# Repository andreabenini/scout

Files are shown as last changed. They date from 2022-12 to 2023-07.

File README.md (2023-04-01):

# scout
All terrain six wheeled scout robot (ATWSC). For fun and the sake of doing it.  
Project inspired by rocker-bogie designs mostly popularized by NASA Mars Missions and
developed around 1988 in JPL Labs. Sojourner was the first wheeled vehicle to rove on
a planet other than Earth, rocker-bogie was used due to its reliability.

---

The rocker-bogie design is unsprung and uses split rather than full-width axles,
allowing the rover to climb over obstacles that are up to twice the wheel's diameter in size
while keeping all six wheels on the ground.  
Systems using springs tend to tip more easily as the loaded side yields.

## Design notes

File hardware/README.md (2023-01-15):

# Raspberry Pi Wiring connections
```mermaid
flowchart LR
    VDC  ---|3.3v | 1...2
    SDA1 ---|SDA  | 3...4
    SCL1 ---|SCL  | 5...6
                    7...8  ---|GPIO14| B_1
    gnd  ---|GND  | 9...10 ---|GPIO15| B_2
                   11...12 ---|GPIO18| B_3
                   13...14 ---|GND   | B_gnd

    subgraph GPIO
         1...2
         3...4
         5...6
         7...8
         9...10
        11...12
        13...14
    end
    subgraph I2C
        VDC
        SDA1
        SCL1
        gnd
    end
    subgraph Buttons
        direction LR
        B_1
        B_2
        B_3
        B_gnd
    end
```

# PCA 9685 Connection Schema
| PCA 9685  | Pro Micro | _notes_ |
|:---:|:---:|---|
| **GND** | GND | |
| **OE** | __ | _not connected_ |
| **SCL** | SCL | _ProMicro SCL_ |
| **SDA** | SDA | _ProMicro SDA_ |
| **VCC** | RAW | _5v input from RAW_ |
| **V+** | __ | _not connected_ |

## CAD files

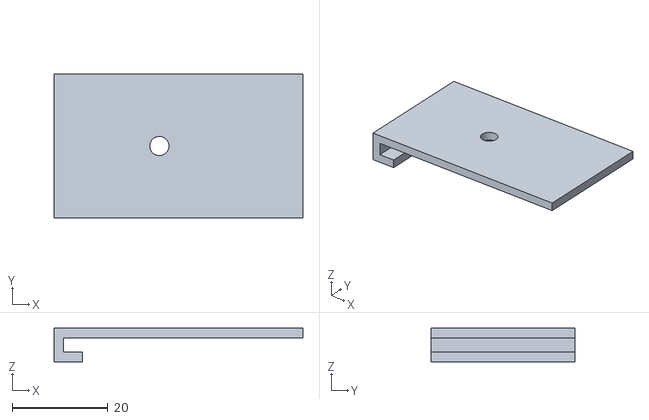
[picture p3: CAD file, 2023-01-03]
hardware/Chassis-Button Base.stl
52.0 x 30.0 x 7.00

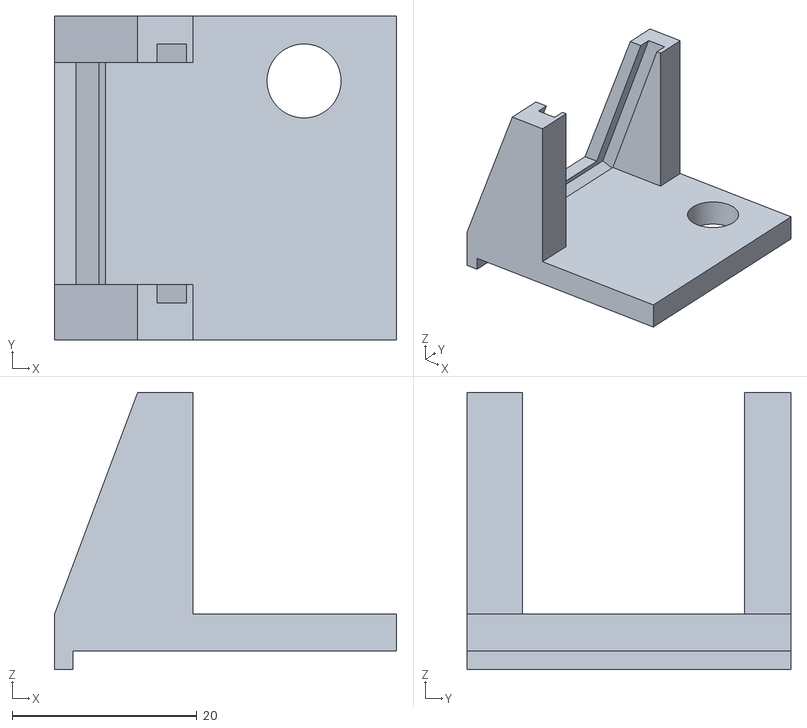
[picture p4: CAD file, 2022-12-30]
hardware/Chassis-service monitor holder.stl
37.0 x 35.0 x 30.0

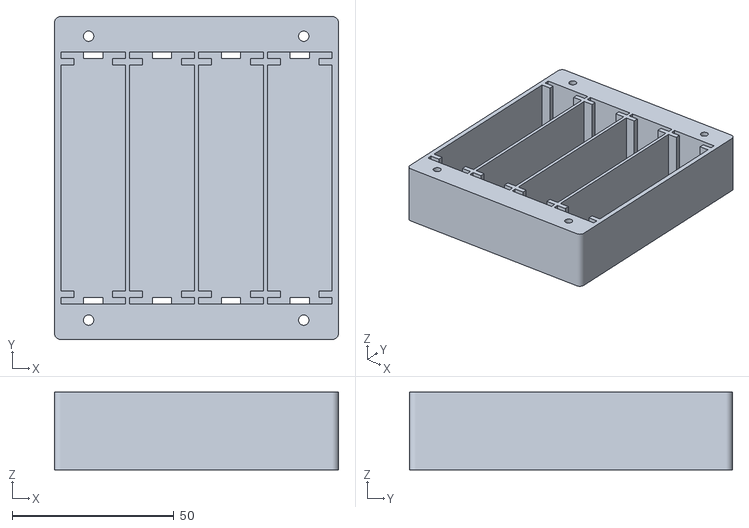
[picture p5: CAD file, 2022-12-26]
hardware/battery pack-BatteryBox.stl
88.0 x 100.0 x 24.0

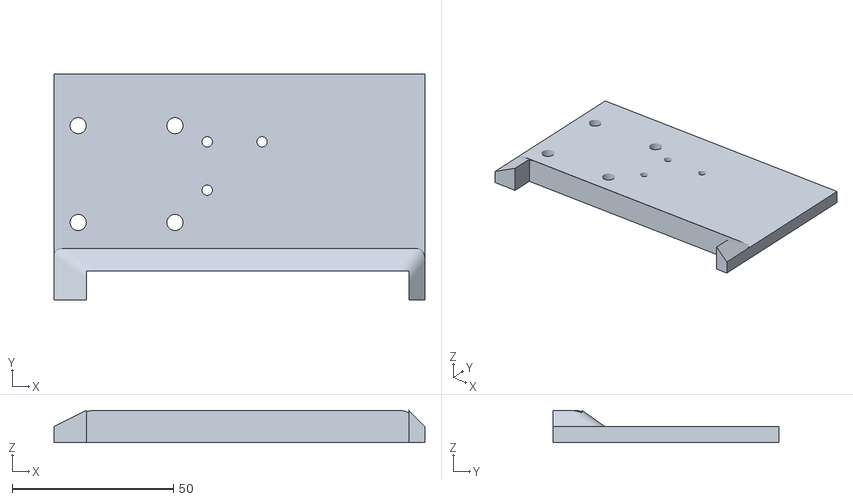
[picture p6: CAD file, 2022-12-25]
hardware/Chassis-Wing Left.stl
115.0 x 70.0 x 10.0

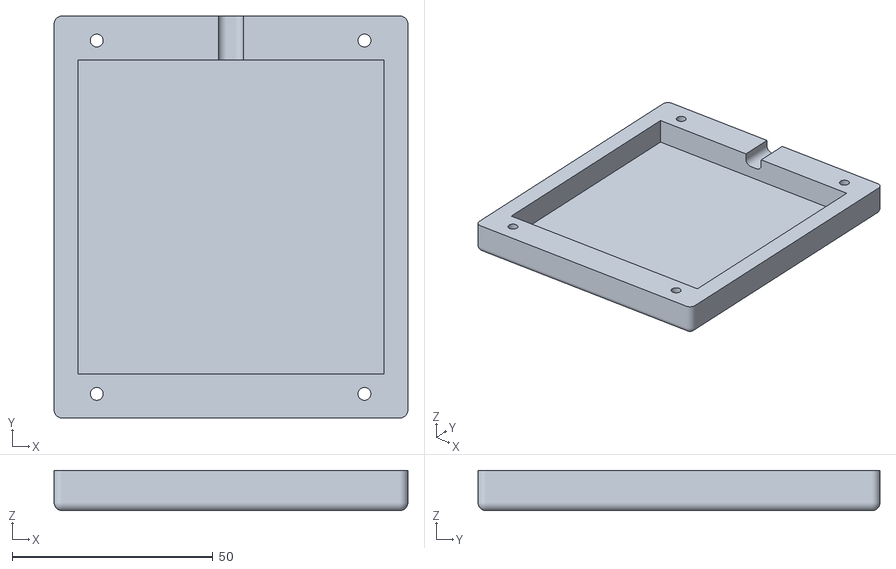
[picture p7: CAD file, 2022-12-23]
hardware/battery pack-Battery Bottom.stl
88.0 x 100.0 x 10.0

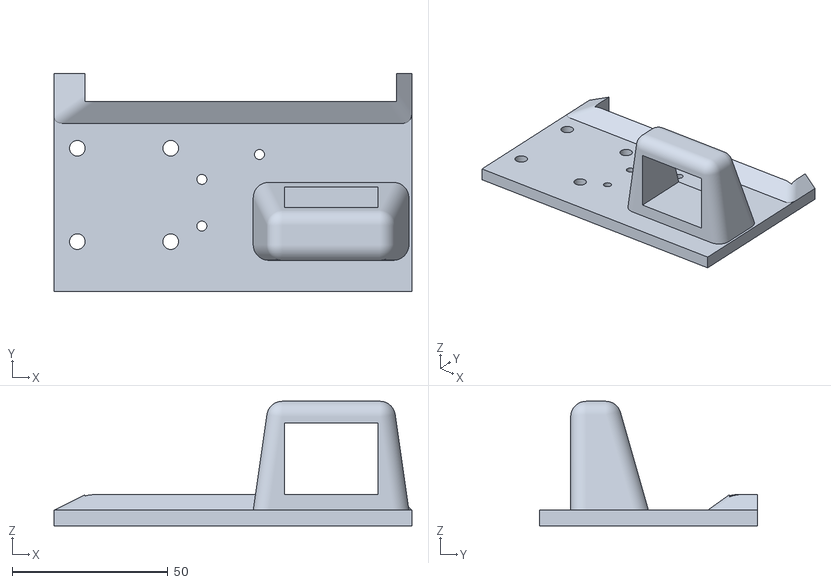
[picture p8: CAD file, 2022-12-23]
hardware/Chassis-Wing Right.stl
115.0 x 70.0 x 40.0

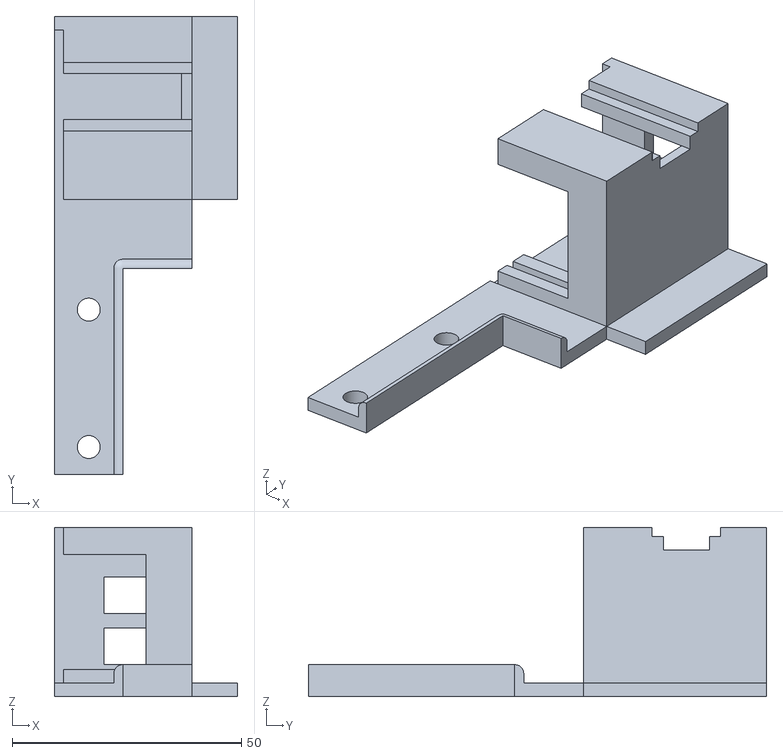
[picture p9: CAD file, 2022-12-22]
hardware/Chassis-Power Strip Box.stl
40.0 x 100.0 x 37.0

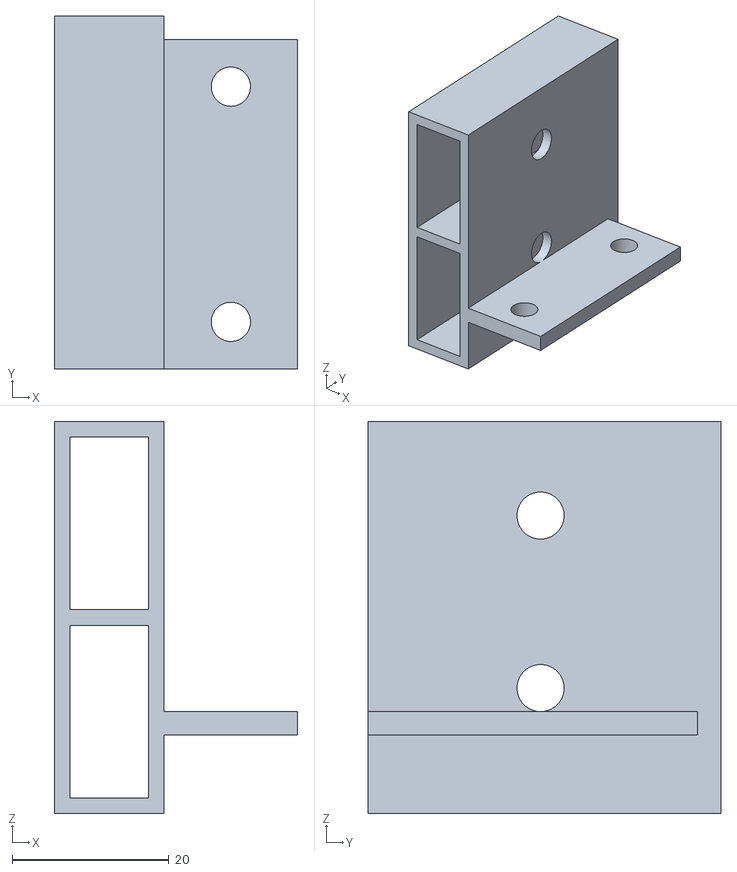
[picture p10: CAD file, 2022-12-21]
hardware/Chassis-UBECs.stl
31.0 x 45.0 x 50.0

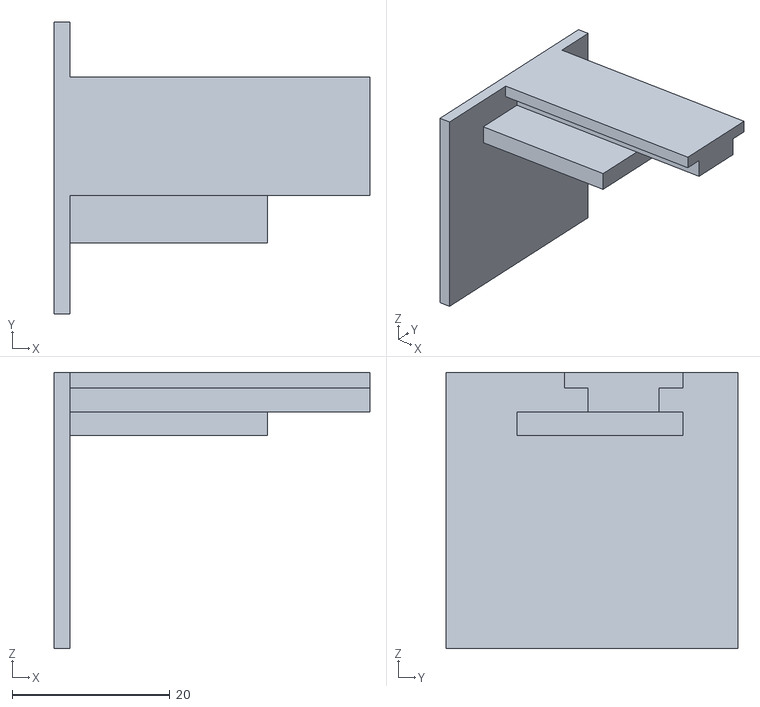
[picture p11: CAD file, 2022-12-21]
hardware/Chassis-Power Strip Cover.stl
40.0 x 37.0 x 35.0

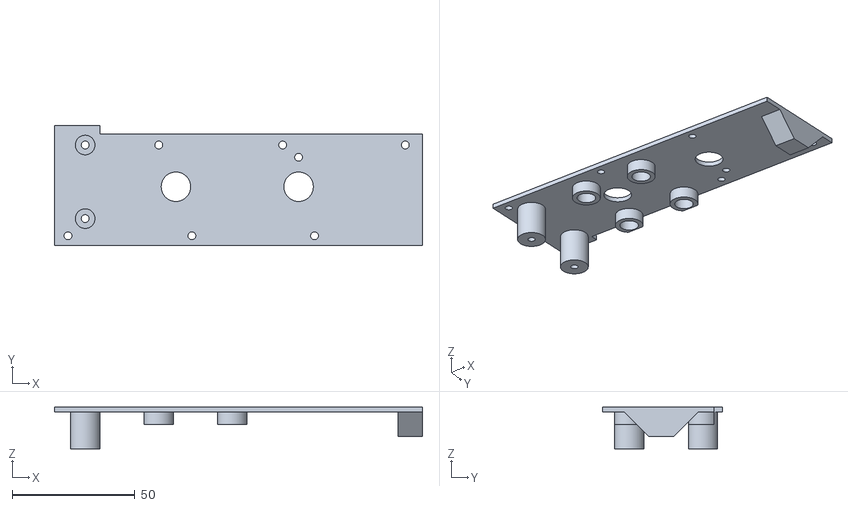
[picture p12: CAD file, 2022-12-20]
hardware/Chassis-HBridge Deck.stl
150.0 x 49.0 x 17.0

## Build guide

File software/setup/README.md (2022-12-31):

# System Setup

## Required Packages
These packages are needed for barebone software setup, everything else will
be installed as a dependency
- git
- gcc
- rsync
- i2c-tools  
    I2C Devices
- python
- python-pillow  
    I2C oled display

## I2C Setup
**/boot/config.txt**
```
dtparam=i2c_arm=on
```
**/etc/modules-load.d/raspberrypi.conf**, add i2c kernel module to this file
```sh
i2c-dev
```
### System check
- `lsmod |grep i2c_dev`
- `ls -la /dev/i2c-1`, might be _i2c-0_ if you've an older machine. 
    **i2c-20**, **i2c-21** are the HDMI output ports
- `i2cdetect -y 1`, where **1** is related to `i2c-1`, change it accordingly.
    This should print the I2C setup on GPIO port 1
- `i2cdetect -l`, displays the list of I2C Buses available in your system. Reference
    to i2c-20 and i2c-21 to **Broadcom STB** are related to HDMI ports

## Python Virtual Enviornment
These packages are needed, create a virtual environment and install them all in this order.
There's no need to execute everything in a privileged environment, normal user is preferred.
- wheel
- adafruit-circuitpython-ssd1306  
    I2C oled display
- RPi-GPIO
- Pillow  
    I2C oled graphical capabilities and animations

### I2C Display Samples
- **PREFERRED**, use this library for some OLED display samples:  
    https://github.com/adafruit/Adafruit_CircuitPython_SSD1306  
    This one is using CircuitPython libs
- **DEPRECATED**, do _NOT_ use this one:  
    https://github.com/adafruit/Adafruit_Python_SSD1306  
    this lib is still using the old _python-wiring_ as backend, it has
    been discontinued from RPi Foundation, use circuit python based one

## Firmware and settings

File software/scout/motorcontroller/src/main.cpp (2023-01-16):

// Libraries defines
#include <Arduino.h>
#include <Adafruit_PWMServoDriver.h>

// Global variables
byte iCommand;
char BUFFER[200];
char Command[50];

// Project defines
#include "defines.h"
#include "common.h"
#include "motor.h"
#include "communication.h"


/**
 * Global variables
 */
Adafruit_PWMServoDriver pwm;


/**
 * setup() - Constructor
 */
void setup() {
    serialConnect();
    motorInit();
} /**/


/**
 * loop() - MAIN LOOP
 */
void loop() {
    // Command detection
    if (iCommand > 0) {
        serialGetCommand();
        if (!strncmp_P(Command, CMD_MOTOR, strlen_P(CMD_MOTOR))) {
            motorCommand(Command);
        } else if (!strcmp_P(Command, CMD_INFO)) {
            Serial.println(FPrintCMD(INFO_VERSION));
        } else {
            Serial.print(FPrintCMD(CMD_ERROR));
            Serial.print(FPrint(" command: "));
            Serial.println(Command);
        }
    }
    delay(MAIN_LOOP_DELAY);
} /**/


/**
 * Generic serial event function, all results ALWAYS in [BUFFER], use [isBuffer] to check if it's complete
 */
void serialEvent() {
    while (Serial.available()) {
        int  iLen  = strlen(BUFFER);
        char iChar = (char)Serial.read();
        BUFFER[iLen] = iChar;
        BUFFER[iLen+1] = '\0';
        if (iChar == '\n') {
            iCommand++;
        }
    }
} /**/
/** NOTE: ProMicro does NOT use standard 'serialEvent()' but 'serialEventRun()' instead, adding both for compatibility */
void serialEventRun() { serialEvent(); }

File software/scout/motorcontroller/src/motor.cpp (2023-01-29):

#include "motor.h"

/**
 * INIT Motor Pins
 */
void motorInit() {
    Adafruit_PWMServoDriver pwm = Adafruit_PWMServoDriver();        // (const uint8_t addr)
    pwm.begin();
    /**
     * In theory the internal oscillator (clock) is 25MHz but it really isn't that precise. 
     * You can 'calibrate' this by tweaking this number until you get the PWM update frequency you're expecting !
     * The int.osc. for the PCA9685 chip is a range between about 23-27MHz and is used for calculating things like writeMicroseconds()
     * Analog servos run at ~50 Hz updates, It is importaint to use an oscilloscope in setting the int.osc frequency for the I2C PCA9685 chip.
     *     1) Attach the oscilloscope to one of the PWM signal pins and ground on the I2C PCA9685 chip you are setting the value for.
     *     2) Adjust setOscillatorFrequency() until the PWM update frequency is the expected value (50Hz for most ESCs)
     * Setting the value here is specific to each individual I2C PCA9685 chip and affects the calculations for the PWM update frequency. 
     * Failure to correctly set the int.osc value will cause unexpected PWM results
     */
    pwm.setOscillatorFrequency(27000000);
    pwm.setPWMFreq(1600);                   // Max PWM frequency
    /**
     * if you want to really speed stuff up, you can go into 'fast 400khz I2C' mode.
     * Some i2c devices dont like this so much so if you're sharing the bus, watch out for this!
     */
    Wire.setClock(400000);
} /**/


/**
 * Detect motor command
 * @see Command:   motor <Motor> [direction] [DutyCycle]
 *                      Motor     (0..6)    0 means all motors (default: 0)
 *                      Direction (0..1)    0: Forward, 1: Backward.  Default: 0,forward
 *                      DutyCycle (0..100)  Motor duty cycle (0: OFF, 100: Full throttle), default: 0
 */
void motorCommand(char *command) {
    byte motor = 0;
    byte direction = 0;
    unsigned int dutyCycle = 0;             // FIXME: Need to be switched back to byte
    const char delimiter[] = " ";
    char *token = strtok(command, delimiter);
    if (token != NULL) {                    // Command
        token = strtok(NULL, delimiter);    // Motor
        motor = atoi(token);
        if (motor > MOTOR_NUMBER) {
            motor = 0;
        }
        token = strtok(NULL, delimiter);    // Direction
        direction = atoi(token);
        if (direction > 1) {
            direction = 0;
        }
        token = strtok(NULL, delimiter);    // Duty Cycle
        dutyCycle = atol(token);
        // if (dutyCycle > 100) {           // FIXME: Temporarily removing duty cycle controls
        //     dutyCycle = 100;
        // }
        Serial.println(FPrintCMD(CMD_OK));
        // Do something with [motor] and [dutycycle]
        if (motor == 0) {
            for (motor=1; motor<=MOTOR_NUMBER; motor++) {
                motorAction(motor, direction, dutyCycle);
            }
        } else {
            motorAction(motor, direction, dutyCycle);
        }
    }
} /**/


void motorAction(byte motorNumber, byte direction, unsigned int dutyCycle) {        // FIXME: Take [dutyCycle] back to byte
    // DEBUG:
    Serial.print("Motor: ");
    Serial.print(motorNumber);
    Serial.print("   Direction (");
    Serial.print(direction);
    Serial.print(") ->    DutyCycle ");
    Serial.println(dutyCycle);
    // DEBUG: End

    /*
     *   @param  num One of the PWM output pins, from 0 to 15
     *   @param  val The number of ticks out of 4096 to be active, should be a value from 0 to 4095 inclusive.
     *   @param  invert If true, inverts the output, defaults to 'false'
     */
    // pwm.setPin(motorNumber-1, 4096*dutyCycle/100, direction==0? true: false);    // FIXME: Use this one with the 0..100% scale
    // DEBUG: PWM debug with direct commands to PWMServoDriver
    pwm.setPin(motorNumber-1, dutyCycle, direction==0? true: false);
    
    // pwm.setPWM(motorNumber, 0, (i + (4096/16)*motorNumber) % 4096 );
    // setPin(uint8_t num, uint16_t val, bool invert)
}

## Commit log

2022-12-19 UBECs holder
    [Chassis-UBECs.stl]
2022-12-19 mechanical designs
    [Chassis-UBECs.stl]
2022-12-20 Chassis mods on lower bridge adapting mounting options - BEC redesign with more space inside - HBridge disposal on the left wing
    [Chassis-HBridge Deck.stl, Chassis-UBECs.stl]
2022-12-21 New power strip box for 5v and 12v
    [Chassis-Power Strip Box.stl, Chassis-Power Strip Cover.stl]
2022-12-21 Larger ubec box, more space for BECs
    [Chassis-UBECs.stl]
2022-12-22 Reinforced base and improved smooth running drawer
    [Chassis-Power Strip Box.stl]
2022-12-23 Right side of the battery
    [Chassis-Wing Right.stl]
2022-12-23 improved back battery pack (thin and clean)
    [battery pack-Battery Bottom.stl]
2022-12-25 Robot left wing
    [Chassis-Wing Left.stl]
2022-12-26 Battery pack box
    [battery pack-BatteryBox.stl]
2022-12-30 small 1" service monitor holder for RPi
    [Chassis-service monitor holder.stl]
2023-01-03 GPIO wiring diagram
2023-01-03 Base button holder
    [Chassis-Button Base.stl]
2023-01-06 sync data script from/to PC to/from Device
2023-01-07 infoDisplay Button Keyboard daemon
2023-01-09 PlatformIO project for motor controller software
2023-01-10 motor controller defines
2023-01-11 barebone skeleton for the motorcontroller program
2023-01-14 Arduino Pro Micro detection script
2023-01-16 early stage microcontroller program, using PWMlibs
2023-01-21 motor debug
2023-01-29 debugging on motors with direct PWM control
